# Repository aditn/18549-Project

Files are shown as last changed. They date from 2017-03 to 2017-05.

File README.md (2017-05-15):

# PSTR - posture
Project website:
<a href="https://www.ece.cmu.edu/~ece549/spring17/team15/website/"> PSTR official website </a>
Project video link:
N/A (working on it now)

### This is a CMU 18549 project done by Team 15 with the following Team members:
 -  Benson Zhang (yaxiangz)

 - Adit Namdev (anamdev)

 - Tony Jin (tdjin)

 - Nikhil Nilakantan (nnilakan)

## System components

1. Hardware
    > Maintainers: Adit & Nikil

2. Software
    > Maintainers: Benson & Tony

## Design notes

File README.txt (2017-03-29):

Sample demo JSON:
{'sensor1': <float>,
 'sensor2': <float>,
 'sensor3': <float>,
 'sensor4': <float>,
 'timestamp': <String>}

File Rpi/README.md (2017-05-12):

<-------------POST-------------->

For Data: <br />
URL = http://pstr-env.us-east-2.elasticbeanstalk.com:80 <br />

JSON Format: <br />
{'sensor1': (float), <br />
 'sensor2': (float), <br />
 'sensor3': (float), <br />
 'sensor4': (float), <br />
 'fsr1': (float), <br />
 'fsr2': (float), <br />
 'fsr3': (float)} <br />

For Users: <br />
URL = http://pstr-env.us-east-2.elasticbeanstalk.com:80/user <br />

JSON Format: <br />
{'user': (String)} <br />
max 20 characters

<--------------GET---------------->

GET request JSON array format:

GET URL: http://pstr-env.us-east-2.elasticbeanstalk.com:80/data2 <br />

JSON Format: <br />
[{'id': (int), <br />
  'user': (String), <br />
  'sb_l_weight': (float), // seat cushion back left sensor <br />
  'sb_r_weight': (float), // seat cushion back right sensor <br />
  'sf_l_weight': (float), // seat cushion front left sensor <br />
  'sf_r_weight': (float), // seat cushion front right sensor <br />
  'st': (float), // seat tailbone sensor <br />
  'bl': (float), // seat lower back sensor <br />
  'bu': (float), // seat upper back sensor <br />
  'sb_l_perc': (float), // seat cushion back left weight percentage (0-1) <br />
  'sb_r_perc': (float), // seat cushion back rightweight percentage (0-1) <br />
  'sf_l_perc': (float), // seat cushion front left weight percentage (0-1) <br />
  'sf_r_perc': (float), // seat cushion front right weight percentage (0-1) <br />
  'seated': (int), // 1 for seated, 0 for not seated <br />  
  'correct': (int), // 1 for correct posture, 0 for incorrect posture <br />
  'score': (float), // posture score (0-1) <br />
  'status_msg': (String), // status message for usual cases of good/bad posture. will sometimes be empty string for unusual cases <br />
  'timestamp': (timestamp)},
 {...},
 {...}]

Optional parameters: {'number' = (int), 'user' = (String)}<br />
If 'number' specified, will give the N most recent entries. Otherwise gives all entries.<br />
If 'user' specified, will give the data for that user. Otherwise gives the data for the default test user.

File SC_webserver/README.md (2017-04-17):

# Smart Chair Backend

## basic usage:

> 'node server.js'
or
> 'node start'

At our first stage, this should allow listening to a port at localhost and return simple responses.

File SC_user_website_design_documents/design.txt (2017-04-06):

This is a simple text file to illustrate my idea of our user website.

The basic design for our user website includes two parts:
1. user
2. admin

Both parts will require login (identification).
Thus both parts will be able to:
    a. set their passwords/username

For 1. user, they can
    b. view their activities in a non-interactive way
    c. set the sensors to learning mode

For 2. admin, they can
    d. view all "chairs" activities
        d.1. A chair is simply defined by a set of sensors
        d.2. If in the case that any sensors are broken,
             it is still viewed as a chair, simply not complete.
             In this case, there will be demonstration of which sensor is not
             sending data.
    e. toggle monitoring mode
        e.1. monitoring mode is a mode at which admin can leave the website,
             and any 'illegal' activities will be reported to a preset mail
             address.

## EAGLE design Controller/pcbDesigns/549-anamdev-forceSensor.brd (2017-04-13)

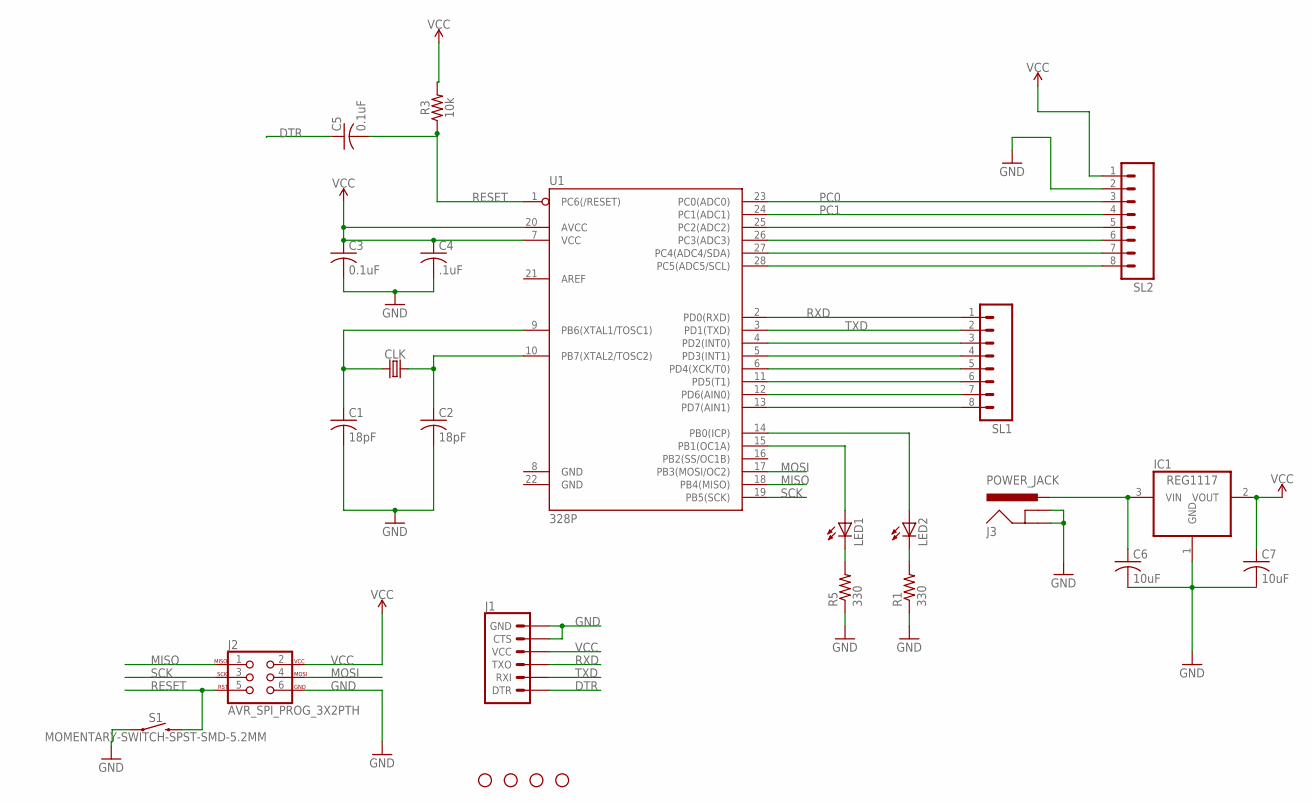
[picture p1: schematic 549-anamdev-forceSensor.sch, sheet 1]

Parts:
C1, C2: 18pF; C1206
C3, C5: 0.1uF; C1206
C4: .1uF; C1206
C6, C7: 10uF; C1206
CLK: CRYSTALSMD-HC49UP; HC49UP
H1, H2, H3, H4: STAND-OFF
IC1: REG1117; SOT223
J1: 6_PIN_SERIAL_TARGET; 1X06
J2: AVR_SPI_PROG_3X2PTH; 2X3
J3: POWER_JACK; POWER_JACK_PTH
LED1, LED2: LED1206; LED-1206
R1, R5: 330; R1206
R3: 10k; 1206
S1: MOMENTARY-SWITCH-SPST-SMD-5.2MM; TACTILE_SWITCH_SMD_5.2MM
SL1, SL2: M08; 08P
U1: 328P; DIP28

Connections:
DTR: C5.1, J1.1 (DTR)
GND: C1.2, C2.2, C3.2, C4.2, C6.2, C7.2, IC1.1 (GND), J1.5 (CTS), J1.6 (GND), J2.6, J3.GND, J3.GNDBREAK, R1.1, R5.1, S1.1, SL2.2; also elsewhere on the board
MISO: J2.1, U1.18 (PB4(MISO))
MOSI: J2.4, U1.17 (PB3(MOSI/OC2))
unnamed: LED2.A, U1.14 (PB0(ICP))
unnamed: LED1.C, R5.2
unnamed: LED1.A, U1.15 (PB1(OC1A))
unnamed: LED2.C, R1.2
unnamed: C6.1, IC1.3 (VIN), J3.PWR
unnamed: SL2.6, U1.26 (PC3(ADC3))
unnamed: SL1.5, U1.6 (PD4(XCK/T0))
unnamed: SL1.6, U1.11 (PD5(T1))
unnamed: SL1.7, U1.12 (PD6(AIN0))
unnamed: SL1.8, U1.13 (PD7(AIN1))
unnamed: SL1.3, U1.4 (PD2(INT0))
unnamed: SL1.4, U1.5 (PD3(INT1))
unnamed: C1.1, CLK.1, U1.9 (PB6(XTAL1/TOSC1))
unnamed: C2.1, CLK.2, U1.10 (PB7(XTAL2/TOSC2))
PC0: SL2.3, U1.23 (PC0(ADC0)); also elsewhere on the board
PC1: SL2.4, U1.24 (PC1(ADC1)); also elsewhere on the board
PC2: SL2.5, U1.25 (PC2(ADC2))
RESET: C5.2, J2.5, R3.1, S1.3 (2), U1.1 (PC6(/RESET))
RXD: J1.3 (TXO), SL1.1, U1.2 (PD0(RXD))
SCK: J2.3, U1.19 (PB5(SCK)); also elsewhere on the board
SCL: SL2.8, U1.28 (PC5(ADC5/SCL))
SDA: SL2.7, U1.27 (PC4(ADC4/SDA))
TXD: J1.2 (RXI), SL1.2, U1.3 (PD1(TXD))
VCC: C3.1, C4.1, C7.1, IC1.2 (VOUT), J1.4 (VCC), J2.2, R3.2, SL2.1, U1.7 (VCC), U1.20 (AVCC); also elsewhere on the board

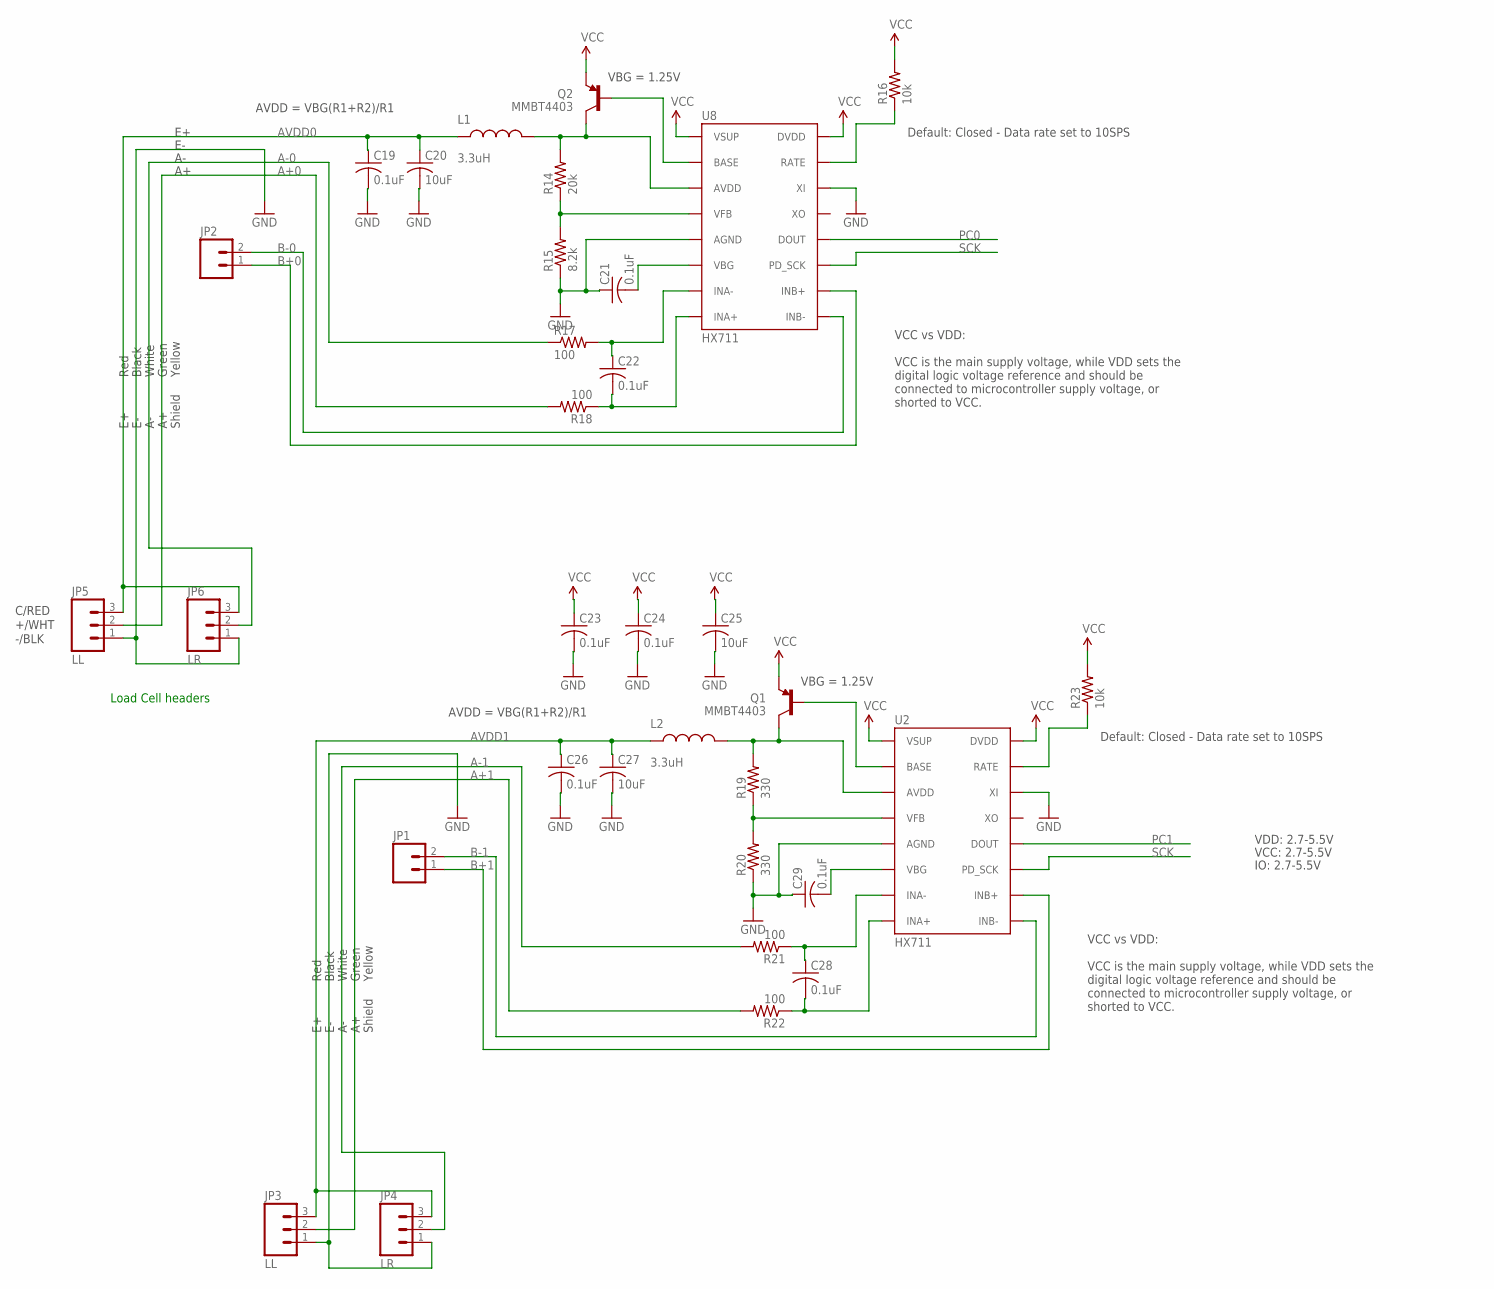
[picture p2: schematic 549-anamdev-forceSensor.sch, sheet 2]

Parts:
C19, C21, C22, C23, C24, C26, C28, C29: 0.1uF; C1206
C20, C25, C27: 10uF; C1206
JP1, JP2: M02PTH; 1X02
JP3, JP5: LL; 1X03
JP4, JP6: LR; 1X03
L1, L2: 3.3uH; 0805
Q1, Q2: MMBT4403; SOT23-3
R14: 20k; R1206
R15: 8.2k; R1206
R16, R23: 10k; R1206
R17, R18, R21, R22: 100; R1206
R19, R20: 330; R1206
U2, U8: HX711; SO16

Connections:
A+0: JP5.2, R18.2
A+1: JP3.2, R22.2
A-0: JP6.2, R17.1
A-1: JP4.2, R21.2
AVDD0: C19.1, C20.1, JP5.3, JP6.3, L1.1
AVDD1: C26.1, C27.1, JP3.3, JP4.3, L2.1
B+0: JP2.1, U8.10 (INB+)
B+1: JP1.1, U2.10 (INB+)
B-0: JP2.2, U8.9 (INB-)
B-1: JP1.2, U2.9 (INB-)
GND: C19.2, C20.2, C21.1, C23.2, C24.2, C25.2, C26.2, C27.2, C29.1, JP3.1, JP4.1, JP5.1, JP6.1, R15.1, R20.1, U2.5 (AGND), U2.14 (XI), U8.5 (AGND), U8.14 (XI); also elsewhere on the board
unnamed: Q2.1 (B), U8.2 (BASE)
unnamed: R14.1, R15.2, U8.4 (VFB)
unnamed: C21.2, U8.6 (VBG)
unnamed: L1.2, Q2.3 (C), R14.2, U8.3 (AVDD)
unnamed: R16.1, U8.15 (RATE)
unnamed: C22.1, R17.2, U8.7 (INA-)
unnamed: C22.2, R18.1, U8.8 (INA+)
unnamed: Q1.1 (B), U2.2 (BASE)
unnamed: R19.1, R20.2, U2.4 (VFB)
unnamed: C29.2, U2.6 (VBG)
unnamed: L2.2, Q1.3 (C), R19.2, U2.3 (AVDD)
unnamed: R23.1, U2.15 (RATE)
unnamed: C28.1, R21.1, U2.7 (INA-)
unnamed: C28.2, R22.1, U2.8 (INA+)
PC0: U8.12 (DOUT); also elsewhere on the board
PC1: U2.12 (DOUT); also elsewhere on the board
SCK: U2.11 (PD_SCK), U8.11 (PD_SCK); also elsewhere on the board
VCC: C23.1, C24.1, C25.1, Q1.2 (E), Q2.2 (E), R16.2, R23.2, U2.1 (VSUP), U2.16 (DVDD), U8.1 (VSUP), U8.16 (DVDD); also elsewhere on the board

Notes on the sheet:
VBG = 1.25V
AVDD = VBG(R1+R2)/R1
Default: Closed - Data rate set to 10SPS
VCC vs VDD: VCC is the main supply voltage, while VDD sets the digital logic voltage reference and should be connected to microcontroller supply voltage, or shorted to VCC.
Red
Black
White
Green
-/BLK
+/WHT
C/RED
Shield
Yellow
Load Cell headers
VCC: 2.7-5.5V
IO: 2.7-5.5V
VDD: 2.7-5.5V

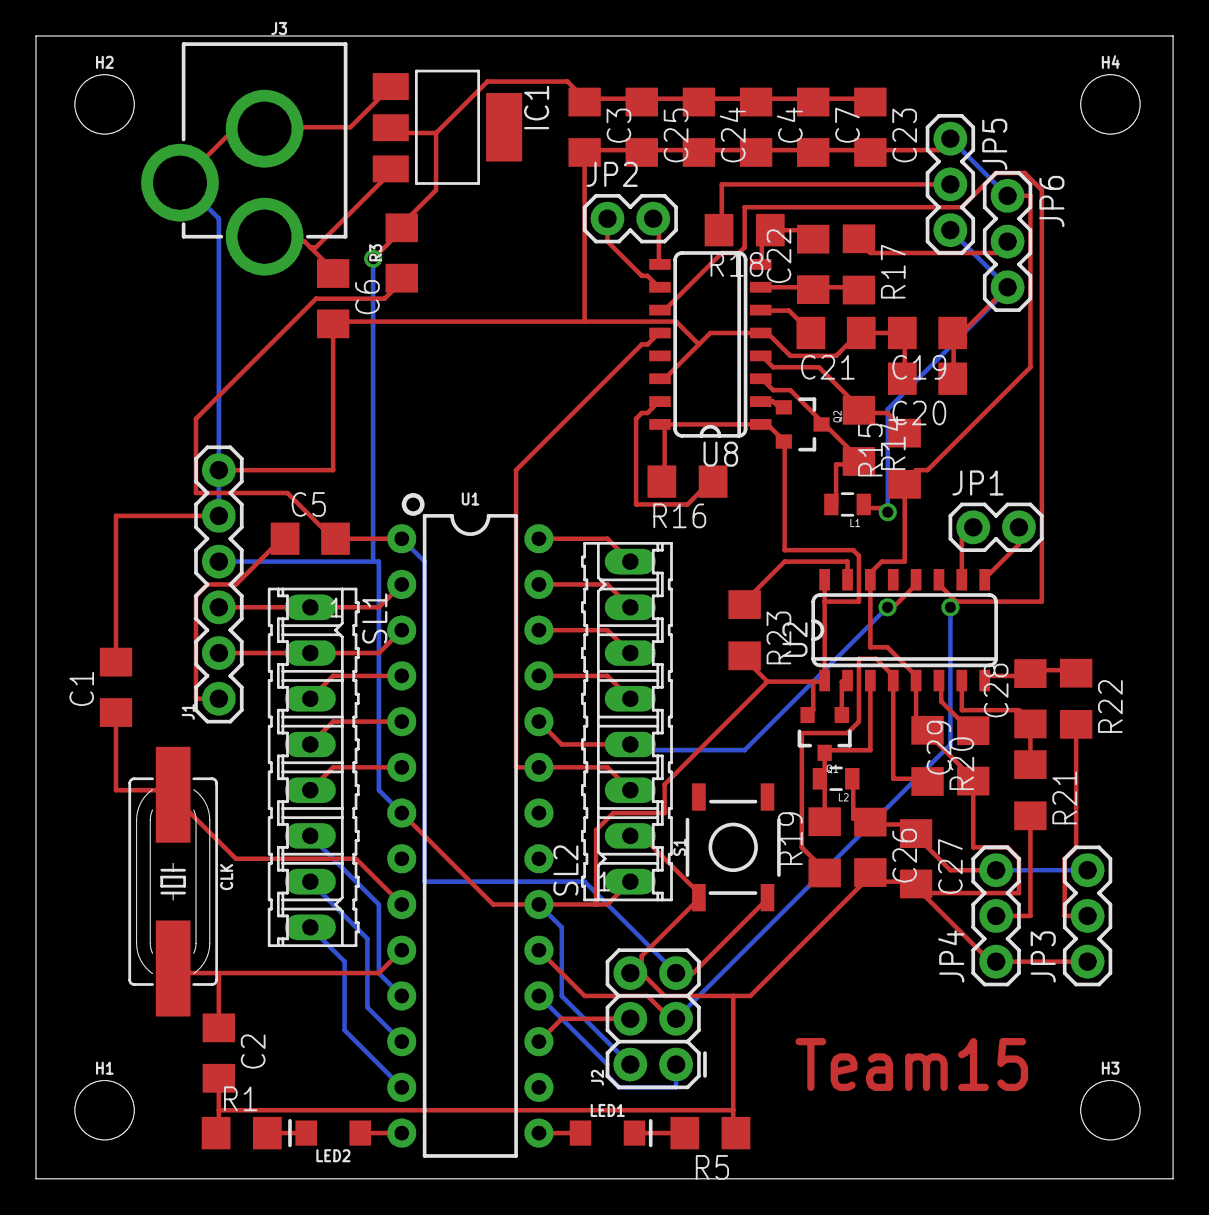
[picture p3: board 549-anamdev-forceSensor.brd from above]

Board: 2 copper layers, 63.2 x 63.5 mm, 58 parts (0 on the bottom side), 52 nets.

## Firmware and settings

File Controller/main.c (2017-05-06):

/*
  main.c
*/

//#include "serial.h"
#include "sensor.h"
#include "uart_test.h"
#include "I2CSlave.h"
#include <util/twi.h>
#include <util/delay.h>
#include <avr/interrupt.h>
#include <string.h>
#include "i2c_comm.h"
#include "main.h"


int main(void)
{
   // Setup serial port
   uart_init();
   stdout = &uart_output;
   stdin  = &uart_input;
   //char input;

   // Setup ports
   DDRB |= (1<<1) | (1<<0);
   PORTB |= (1<<0);
   PORTB &= ~(1<<1);
   
   
   
   // Setup Sensors
   sensor_init();

   //printf("Debounce...\n");
   _delay_ms(1000*10);

   // tare force sensors
   tare();

   // Setup I2C
   I2C_setCallbacks(I2C_received, I2C_requested);
   I2C_init(SLAVE_ADDRESS);
   
   while(1){
     //collectforceData(fData);
     //sendData(fData);
   }
}



// int main(void)
// {
//    // Setup serial port
//    uart_init();
//    stdout = &uart_output;
//    stdin  = &uart_input;
   
//    printf("About to init I2c...\r\n"); 
//    // Setup i2c
//    i2c_init();
//    printf("Completed initialization of I2C!\r\n");

//    char input;

//    // Setup ports
//    DDRB |= (1<<1) | (1<<0);
//    PORTB |= (1<<0);
//    PORTB &= ~(1<<1);

//    /*i2c_init();
//    printf("finished initing\r\n");
//    //i2c_start(DEVREAD);
//    //printf("finished starting\r\n" );
//    //i2c_read_ack();
//    i2c_receive(DEVREAD, accelData, 3);
//    printf("recieved Data\r\n");
//    printf("accelData[0]:%d\n", accelData[0]);
//    */


//   /* Set the LED pin as an output. */
//   //DDRB  |= _BV(LED_PIN);
//   uint8_t pd = 0;
//   uint8_t pd2 = 0;
//   uint8_t waitUntilRed = 0;
//   uint8_t waitUntilGreen = 0;
  
//   /* continually check if the ADC value is greater than the
//    * defined ADC_THRESHOLD value above.  If it is turn the LED on,
//    * if it isn't turn it off. */
//   for (;;) {

//     input = getchar();
//     if(input == 'p'){
//       // use ADC
//       while(1){
//         //for (i = 0; i<5; i++){
//           uint16_t adcVal = adc_read(2);
//           printf("adcVal: %d\r\n", adcVal);
//           if (adcVal>=650) pd = 1;
//           if ((250<=adcVal)&(adcVal<500)) pd2 =1;
//         //}
//         if (pd & !waitUntilGreen) {
//           LED_red_on();
//           waitUntilGreen = 1;
//           waitUntilRed = 0;
//         }
//         if (pd2 & !waitUntilRed){
//           LED_green_on();
//           waitUntilRed = 1;
//           waitUntilGreen = 0;
//         //  _delay_ms(100);
//         }
//         _delay_ms(100);
//         LED_red_off();
//         LED_green_off();
//         //else LED_both_off();
//         pd = 0;
//         pd2 = 0;

//         //if ((input = getchar())=='s') break; // stop probing pulse sensor
//         //_delay_ms(700);
//       }
//       // Probe Pulse Sensor
//       //sensor_probe(); //add macros for each sensor
//       }
//       else if(input == 'l'){
//         // turn on LEDs
//         LED_both_on();
//       }
//       else if(input == 'm'){
//         LED_both_off();
//       }
//       else if(input == 'a'){ //accelerometer
//       }
//       else if(input == 'f'){ //get force sensor data + send to RPi
//         // use ADC here but for now send fake data
//         collectforceData(fData);
//         sendData(fData);

//       }
//       PORTB ^= 0x01;            
//   }


//    /*while(1) {
      
//    }
// */
//   return 0;
// }

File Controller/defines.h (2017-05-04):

#include <avr/io.h>

#define BAUD 115200
#define NUMBER_OF_SENSORS 4
#define SLAVE_ADDRESS 0x04
//#define CALIB_FACTOR -10500

#define SENSOR0 0
#define SENSOR1 1
#define SENSOR2 2
#define SENSOR3 3

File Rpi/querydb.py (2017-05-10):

import requests
import json
import time
  
URL = "http://pstr-env.us-east-2.elasticbeanstalk.com:80/data2"
PARAMS = {'number': 1} # number of rows of most recent data

while True:
    r = requests.get(url=URL, params=PARAMS)
    json = r.json()[0]
    #print json
    print 'Timestamp: ' + json['timestamp']
    print 'sb_l (s1): ' + str(json['sb_l_weight'])
    print 'sb_r (s2): ' + str(json['sb_r_weight'])
    print 'sf_r (s3): ' + str(json['sf_r_weight'])
    print 'sf_l (s4): ' + str(json['sf_l_weight'])
    print 'st (fsr1): ' + str(json['st'])
    print 'bl (fsr2): ' + str(json['bl'])
    print 'bu (fsr3): ' + str(json['bu'])
    time.sleep(1)

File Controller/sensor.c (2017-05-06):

/*
  sensor.c
*/

#include "sensor.h"
#include <avr/interrupt.h>
#include <stdio.h>


void sensor_init(){
   DDRC |= (1<<PC0); // Set PC0(clk) as an output pin
   DDRC &= ~(1<<PC1); // Set PC1(data) as input pin

   SENSORS[SENSOR0].CLK = PC0;
   SENSORS[SENSOR0].DATA = PC1;
   SENSORS[SENSOR0].DIR_REG = &DDRC;
   SENSORS[SENSOR0].PORT_OUTPUT_REG = &PORTC;
   SENSORS[SENSOR0].PORT_INPUT_REG = &PINC;
   SENSORS[SENSOR0].CALIB_FACTOR = -12000;

   /* Initializing second sensor */
   DDRC |= (1<<PC2); // Set PC2(clk) as an output pin
   DDRC &= ~(1<<PC3); // Set PC3(data) as input pin

   SENSORS[SENSOR1].CLK = PC2;
   SENSORS[SENSOR1].DATA = PC3;
   SENSORS[SENSOR1].DIR_REG = &DDRC;
   SENSORS[SENSOR1].PORT_OUTPUT_REG = &PORTC;
   SENSORS[SENSOR1].PORT_INPUT_REG = &PINC;
   SENSORS[SENSOR1].CALIB_FACTOR = -11000;
   /* Initializing second sensor */



   /* Initializing THIRD PORTD sensor */
   DDRD |= (1<<PD7); // Set PD7(clk) as an output pin
   DDRD &= ~(1<<PD6); // Set PD6(data) as input pin

   SENSORS[SENSOR2].CLK = PD7;
   SENSORS[SENSOR2].DATA = PD6;
   SENSORS[SENSOR2].DIR_REG = &DDRD;
   SENSORS[SENSOR2].PORT_OUTPUT_REG = &PORTD;
   SENSORS[SENSOR2].PORT_INPUT_REG = &PIND;
   SENSORS[SENSOR2].CALIB_FACTOR = -11000;
   /* Initializing THIRD PORTD sensor */



   /* Initializing FOURTH PORTB sensor */
   DDRB |= (1<<PB5); // Set PB7(clk) as an output pin
   DDRB &= ~(1<<PB4); // Set PB6(data) as input pin

   SENSORS[SENSOR3].CLK = PB5;
   SENSORS[SENSOR3].DATA = PB4;
   SENSORS[SENSOR3].DIR_REG = &DDRB;
   SENSORS[SENSOR3].PORT_OUTPUT_REG = &PORTB;
   SENSORS[SENSOR3].PORT_INPUT_REG = &PINB;
   SENSORS[SENSOR3].CALIB_FACTOR = -11000;
   /* Initializing THIRD PORTD sensor */

}

uint16_t adc_read(uint8_t adcx) {
  /* adcx is the analog pin we want to use.  ADMUX's first few bits are
   * the binary representations of the numbers of the pins so we can
   * just 'OR' the pin's number with ADMUX to select that pin.
   * We first zero the four bits by setting ADMUX equal to its higher
   * four bits. */
  ADMUX &=  0xf0;
  ADMUX |=  adcx;

  /* This starts the conversion. */
  ADCSRA |= _BV(ADSC);

  /* This is an idle loop that just wait around until the conversion
   * is finished.  It constantly checks ADCSRA's ADSC bit, which we just
   * set above, to see if it is still set.  This bit is automatically
   * reset (zeroed) when the conversion is ready so if we do this in
   * a loop the loop will just go until the conversion is ready. */
  while ( ADCSRA & _BV(ADIF) );

  uint16_t adcV = ADC;
  ADCSRA |= _BV(ADIF);

  /* Finally, we return the converted value to the calling function. */
  return adcV;
}

void adc_init(){
   // disable interrupts
   cli();

   // Set the ADC prescaler to 128 (i.e., 16MHz/128 = 125KHz)
   ADCSRA |= ( 1 << ADPS2 ) | ( 1 << ADPS1 ) | ( 1 << ADPS0 );

   // Set the voltage reference from AVcc (i.e., 5V).
   ADMUX |= ( 1 << REFS0 );

   // Turn on the ADC.
   ADCSRA |= ( 1 << ADEN );

   // Do the initial conversion (i.e., the slowest conversion)
   // to ensure that everything is up and running.
   ADCSRA |= ( 1 << ADSC );
   
   //enable interrupts
   sei();
}

uint32_t read_avg_force(uint8_t sensor_id, uint8_t times){
  uint32_t avg=0;
  uint8_t i;
  for (i=0;i<times;i++){
     avg+=ReadCount(sensor_id);
  }
  avg/=times;
  //printf("avg force value:%lu\n\r",avg);
  return avg;
} 

void tare(){
  uint8_t sensor_id=0;

  for (sensor_id=0; sensor_id < NUMBER_OF_SENSORS; sensor_id++) {
    SENSORS[sensor_id].CALIB_OFFSET = 0;
    SENSORS[sensor_id].CALIB_OFFSET = read_avg_force(sensor_id, 15);
    printf("taring sensor%d:%lu\n\r",sensor_id, SENSORS[sensor_id].CALIB_OFFSET);
  }

  /*
  CALIB_OFFSET = 0;
  CALIB_OFFSET = read_avg_force(); 
  printf("taring sensors:%lu\n\r",CALIB_OFFSET);
  */
}

float read_calibrated_value(uint8_t sensor_id){
  uint32_t avg;
  int32_t avg_offset;
 
  float calib_val=0;
  avg = read_avg_force(sensor_id, 1);
  avg_offset = ((int32_t)avg-SENSORS[sensor_id].CALIB_OFFSET);
  //printf("avg_offset:%li\n\r",avg_offset);
  calib_val = (float)avg_offset/SENSORS[sensor_id].CALIB_FACTOR;
  //printf("calib_val:%f\n\r",calib_val);
 
  return(calib_val);
}

uint32_t ReadCount(uint8_t sensor_id){
  uint32_t Count;
  uint8_t i;

  uint8_t clk = SENSORS[sensor_id].CLK;
  uint8_t data = SENSORS[sensor_id].DATA;
  volatile uint8_t *output_reg = SENSORS[sensor_id].PORT_OUTPUT_REG;
  volatile uint8_t *input_reg = SENSORS[sensor_id].PORT_INPUT_REG;

  /*
  output_reg &= ~_BV(clk);
  output_reg |= _BV(data);

  printf("Saved output_reg is: %d ------ Port value is: %d\r\n", output_reg, PORTC);
  Count=0;

  while(input_reg & _BV(data)); 
  for (i=0;i<24;i++){
    output_reg |= _BV(clk);
    Count=Count<<1;
    output_reg &= ~_BV(clk);
    if(input_reg & _BV(data)) Count++;
  }
  
  output_reg |= _BV(clk);
  Count=Count^0x800000;
  output_reg &= ~_BV(clk);
  */



  *output_reg &= ~_BV(clk);
  *output_reg |= _BV(data);

  //printf("Saved output_reg is: %d ------ Port value is: %d\r\n", *output_reg, PORTC);
  Count=0;

  while(*input_reg & _BV(data)); 
  for (i=0;i<24;i++){
    *output_reg |= _BV(clk);
    Count=Count<<1;
    *output_reg &= ~_BV(clk);
    if(*input_reg & _BV(data)) Count++;
  }
  
  *output_reg |= _BV(clk);
  Count=Count^0x800000;
  *output_reg &= ~_BV(clk);




  /*
  //PC0 is clk
  PORTC &= ~(1<<clk);
  //PC1 is data
  PORTC |= (1<<data); // set PC1 as input

  Count=0;

  while(PINC & (1<<data)); 
  for (i=0;i<24;i++){
    PORTC |= (1<<clk);
    Count=Count<<1;
    PORTC &= ~(1<<clk);
    if(PINC & (1<<data)) Count++;
  }
  
  PORTC |= (1<<clk);
  Count=Count^0x800000;
  PORTC &= ~(1<<clk);
  */

  return(Count);
} 

void collectforceData(float* data){
  // set Data and Manual CLK pins
   
  // using fake data for now
  data[SENSOR0] = read_calibrated_value(SENSOR0);
  //data[0] = (uint32_t)10;
  //data[SENSOR1] = 35.f;
  data[SENSOR1] = read_calibrated_value(SENSOR1);
  //data[2] = (uint32_t)30;
  //data[3] = (uint32_t)40;
  data[SENSOR2] = read_calibrated_value(SENSOR2);

  data[SENSOR3] = read_calibrated_value(SENSOR3);
}


void LED_green_on(){
  DDRC |= (1<<PC0);

  // set PC0 and PC1 to logic 1
  PORTC |= (1<<PC0);
}
void LED_green_off(){
  PORTC &= ~(1<<PC0);
}
void LED_red_on(){
  DDRC |= (1<<PC1);

  // set PC1 to logic 1
  PORTC |= (1<<PC1);
}
void LED_red_off(){
  PORTC &= ~(1<<PC1);
}

void LED_both_on(){
  // set Pins PC0,PC1 as outputs
  //DDRC = 0;
  DDRC |= (1<<PC0) | (1<<PC1);

  // set PC0 and PC1 to logic 1
  PORTC |= (1<<PC0) | (1<<PC1);
}

void LED_both_off(){
  // set Pins PC0,PC1 as outputs
  //DDRC = 0;
  //DDRC |= (1<<PC0) | (1<<PC1);

  // set PC0 and PC1 to logic 1
  PORTC &= ~((1<<PC0) | (1<<PC1));
}

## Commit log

2017-03-21 added first iteration of force sensor board for a single force sensor
    [549-anamdev-forceSensor.brd, 549-anamdev-forceSensor.sch]
2017-03-28 sample json in readme
2017-03-29 added multiple amplifiers for force sensor
    [549-anamdev-forceSensor.brd, 549-anamdev-forceSensor.sch]
2017-04-02 Added basic framework
2017-04-07 updated pcb boards
    [549-anamdev-forceSensor.brd, 549-anamdev-forceSensor.sch]
2017-04-07 cleaned up code and have functioning communication over uart
2017-04-07 Load sensor amp test before calibration
2017-04-10 fixed issue for string parsing
    [uart_test.c]
2017-04-13 fixed issues with pcb
    [549-anamdev-forceSensor.brd]
2017-04-13 added i2c files to Makefile
2017-04-13 adding sensor.h
2017-04-24 Added Rpi i2c test
2017-04-24 Cleaned up Rpi I2C coe to receive real force data
2017-04-25 I2C Working on multiple devices for one byte
2017-04-26 ATMega sending strings over I2C
2017-04-26 Added chair and camera
2017-04-26 Added chair sensor points and simulated data
2017-04-27 Commented main.c and included space to implement force sensor read
2017-04-27 uploaded new server. now can GET fake sensor data. also added sample python get request format
2017-05-01 fixed sensor1 being inputted as null
2017-05-01 fixed rpi post, i2c_comm string format
    [I2C-Test.py, i2c_comm.c]
2017-05-01 Reading force sensor data over I2C
2017-05-02 Added code for multiple sensor reading on one board
2017-05-02 Changed sensor storage to array of structs
2017-05-02 Changed calibration factor definitions
2017-05-03 Fixed multiple sensor feedback
    [i2c_comm.c, main.c, sensor.c]
2017-05-04 Getting feedback from all sensors
2017-05-04 Four sensor functionality
2017-05-05 changed db schema and server to accomodate force pad sensors. added posture checking to server side. updated example GET and POST and README
2017-05-06 added loop to I2C code to query multiple MCUs
2017-05-09 fixed error in query script
    [querydb.py]
2017-05-10 added calibration onto the pi

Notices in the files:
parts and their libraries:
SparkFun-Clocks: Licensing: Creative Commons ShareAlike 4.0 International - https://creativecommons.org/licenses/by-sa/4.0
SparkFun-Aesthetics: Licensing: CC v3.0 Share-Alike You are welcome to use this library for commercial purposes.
